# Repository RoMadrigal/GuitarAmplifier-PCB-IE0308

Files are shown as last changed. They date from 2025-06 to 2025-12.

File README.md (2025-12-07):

# GuitarAmplifier-PCB-IE0308

Repositorio para el proyecto final del curso IE0308 sobre el diseño de una PCB de un amplificador para guitarra. Contiene el circuito esquemático, el diseño de la PCB en *KiCad* y documentación sobre los componentes a utilizar, el procedimiento de diseño y otros detalles. 

Este repositorio y sus contenidos fueron diseñados durante el curso IE0308 durante el periodo I-2025 por los siguientes integrantes del equipo:

<div align="center">

| **Integrantes** | **Carné** | **Correo electrónico**|
|:---:|:---:|:---:|
| Anthony Calvo García | C11433  |  anthonycalvo50@gmail.com |
| Rodrigo Madrigal Montes | C24458  | rmadrigalmontes@gmail.com |

</div>

## Agradecimientos a PCBWay

Queremos expresar nuestro agradecimiento a **PCBWay** por su colaboración y apoyo en la fabricación de nuestras PCBs. La calidad de las placas recibidas, tanto en precisión de fabricación como en acabados, fue sobresaliente. Todo el proceso desde la carga de archivos hasta la recepción del paquete fue ágil, transparente y eficiente. 

Además siempre estuvieron disponibles para cualquier consulta, para asegurarse de que todo saliera según lo planeado, lo cual nos brindó mucho soporte y seguridad durante todo el proceso de pedido.

### PCB ensamblada

Una vez recibidas las placas de **PCBWay**, se procedió con el ensamblaje manual de todos los componentes. A continuación se muestran imágenes del resultado final:

<div align="center">

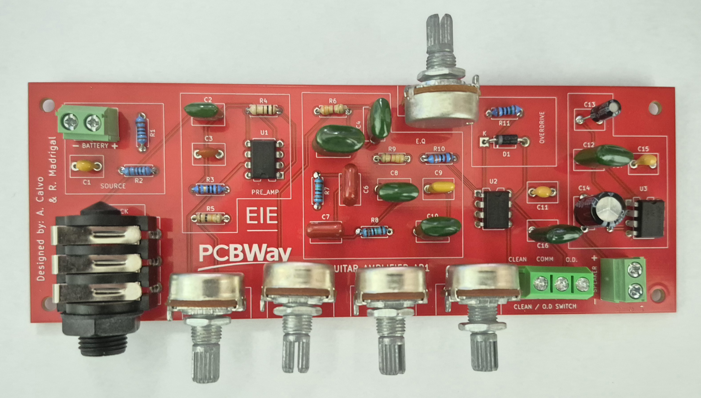
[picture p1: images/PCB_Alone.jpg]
PCB ensamblada - sin los componentes externos conectados
|  |
|:--:|
| *PCB ensamblada - sin los componentes externos conectados* |

</div>

<div align="center">

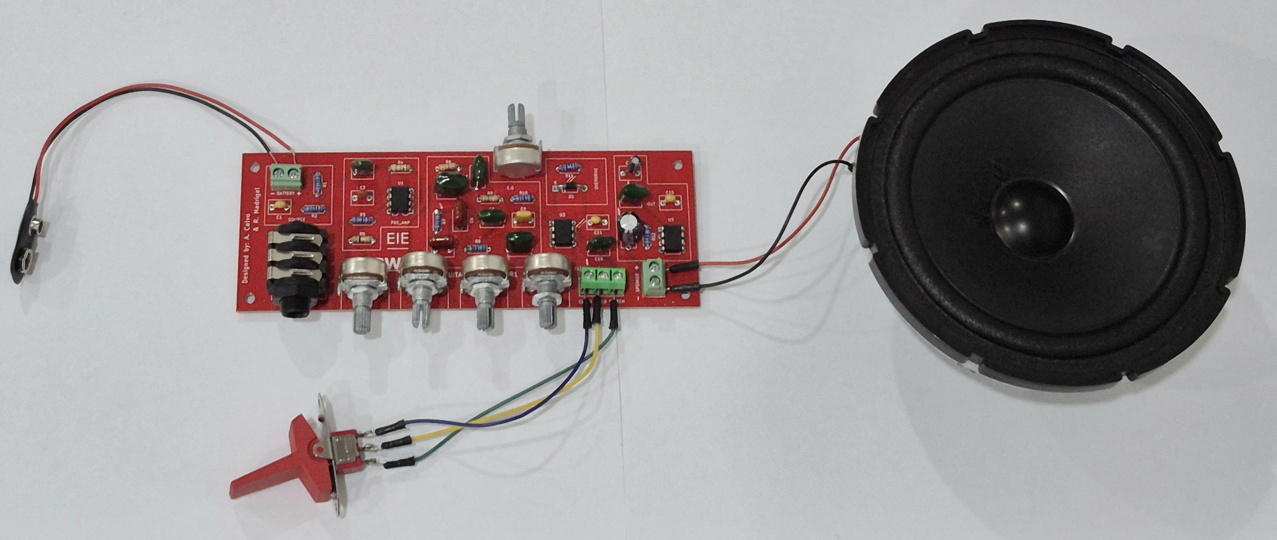
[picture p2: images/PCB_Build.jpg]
PCB ensamblada - con los componentes externos conectados
|  |
|:--:|
| *PCB ensamblada - con los componentes externos conectados* |

</div>

### Demostración de funcionamiento

A continuación, se presentan vídeos demostrativos del amplificador montado, funcionando correctamente tanto con una guitarra eléctrica como con un teléfono:

<p align="center">
  <a href="https://youtu.be/fU8gYd2I1fY" target="_blank">
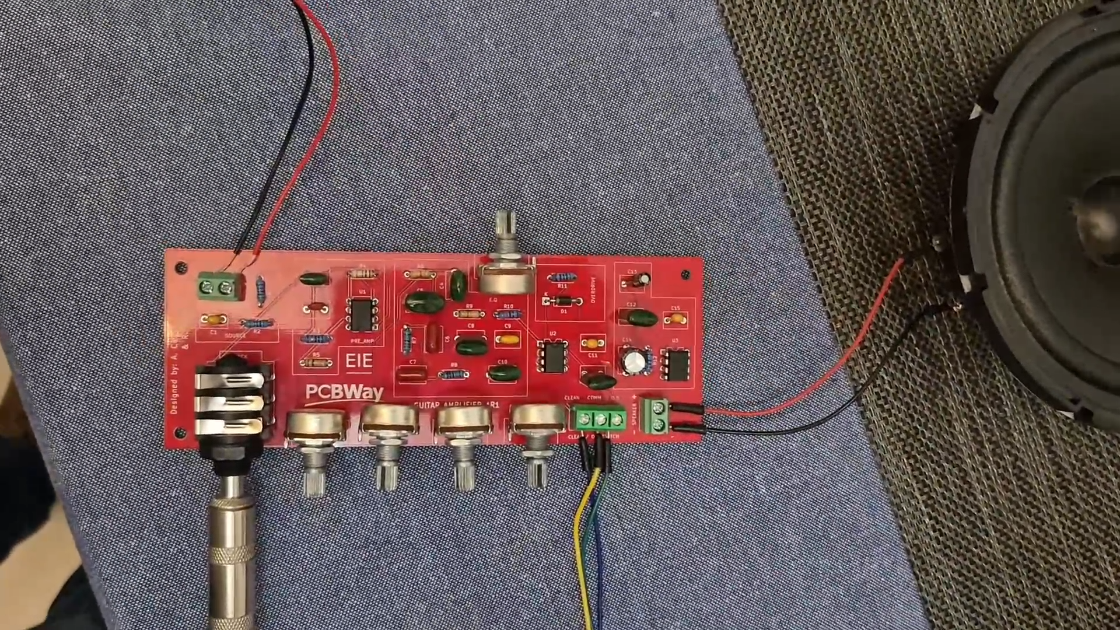
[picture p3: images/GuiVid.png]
Demo con guitarra eléctrica
    
  </a>
  <br/>
  <em>Demostración del amplificador conectado a una guitarra eléctrica</em>
</p>

<p align="center">
  <a href="https://youtu.be/jr76lwe1I88" target="_blank">
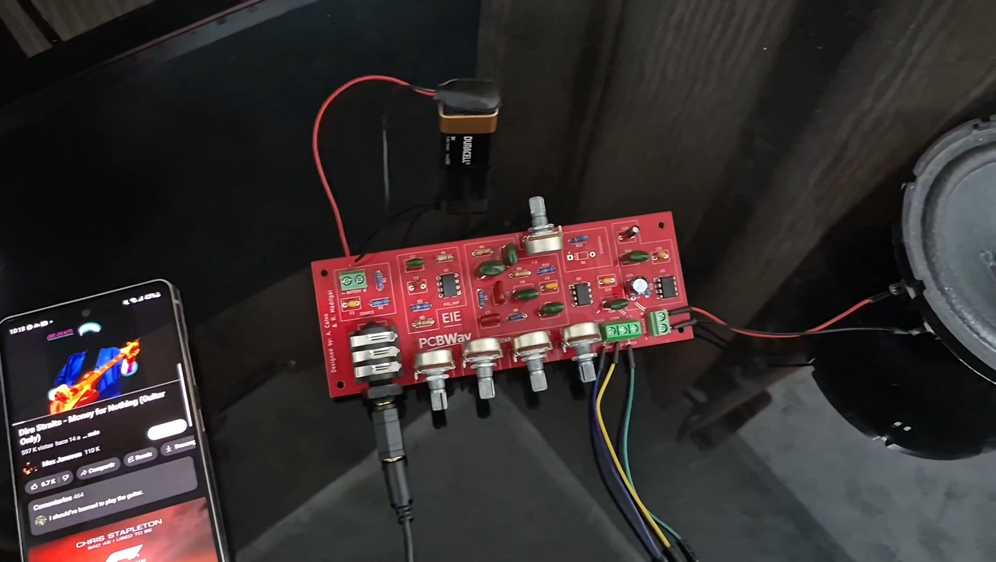
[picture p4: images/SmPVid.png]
Demo con teléfono móvil
    
  </a>
  <br/>
  <em>Demostración del amplificador reproduciendo audio desde un teléfono</em>
</p>

Gracias a su servicio confiable y de altísima calidad, logramos ensamblar y probar con éxito nuestro amplificador, cumpliendo los objetivos del proyecto. Recomendamos sus servicios para estudiantes, profesionales y cualquier persona interesada en manufacturar PCBs de alta calidad. Más información en [pcbway.com](https://www.pcbway.com).

## Organización y contenido de los directorios 

Este repositorio contiene dos directorios principales, cuyos contenidos son:

- `kicad_project`: Contiene los archivos del esquemático, PCB y la configuarción del proyecto
    - `GuitarAmplifier.kicad_pcb`
    - `GuitarAmplifier.kicad_pro`
    - `GuitarAmplifier.kicad_sch`

- `outputs`: Contiene todos los archivos de salida de *KiCad*

Si se desea utilizar este diseño y manufacturarlo por medio de un fabricante se deben comprimir los archivos incluidos en la carpeta `outputs` en un archivo `.zip` y este se puede cargar en la página del fabricante para ordenar la fabricación de la PCB.

## Circuito base

El circuito completo del que partimos para diseñar la PCB fue primeramente fue armado y simulado en el simulador *Tina-TI*:

<div align="center">

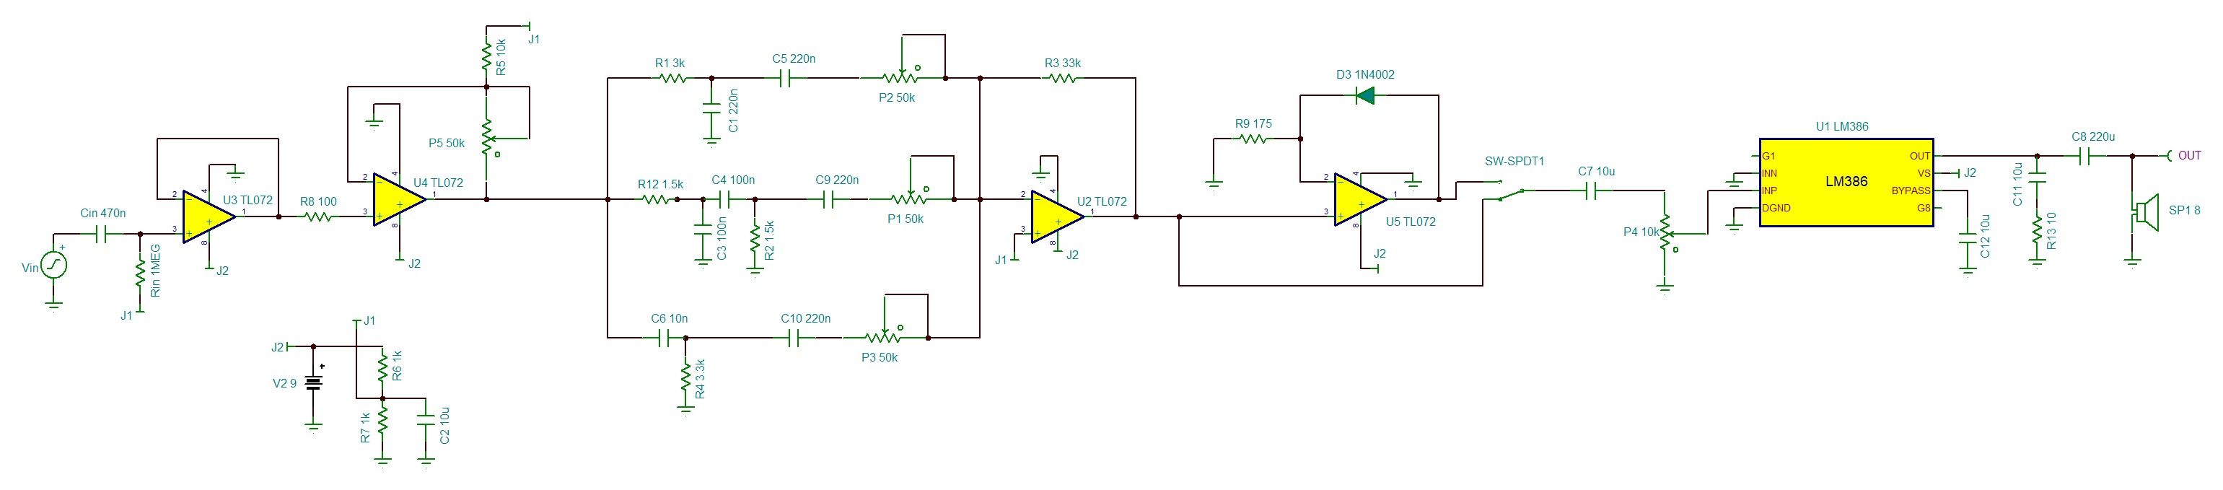
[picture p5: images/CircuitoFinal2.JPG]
Circuto completo del diseño*
|  |
|:--:|
| *Circuto completo del diseño* |

</div>

> [!NOTE]
> La documentación detallada de funcionamiento de cada etapa del circuito, elección de componentes, y consideraciones de diseño está disponible en la documentación adicional asociada al proyecto (ver `Wiki` de este repostitorio).

### Lista de componentes

A continuación se incluye una lista con los componentes utilizados en el diseño, con el mismo número que se les asignó en el diseño final de PCB:

<div align="center">

| Componente | Valor / Modelo | Descripción |
|:---:|:---:|:---:|
| R1 / R2 | 1 kΩ | Resistor de película metálica |
| R3 | 1 MΩ | Resistor de película metálica |
| R4 | 100 Ω | Resistor de película metálica |
| R5 | 10 kΩ | Resistor de película metálica |
| R6 | 3 kΩ | Resistor de película metálica |
| R7 / R8 | 1.5 kΩ | Resistor de película metálica |
| R9 | 3.3 kΩ | Resistor de película metálica |
| R10 | 33 kΩ | Resistor de película metálica |
| R11 | 170 Ω | Resistor de película metálica |
| R12 | 10 Ω | Resistor de película metálica |
| C1 / C3 / C11 / C15 | 470 nF | Capacitor cerámico |
| C2 / C6 / C7 / C12 | 100 nF | Capacitor de poliéster |
| C4 / C5 / C8 / C10 / C16 | 220 nF | Capacitor de poliéster |
| C9 | 10 nF | Capacitor de poliéster |
| C13 | 10 μF | Capacitor electrolítico |
| C14 | 220 μF | Capacitor electrolítico |
| U1 / U2 | TL072CP | Amplificador operacional |
| U3 | LM386 | Amplificador de potencia |
| D1 | 1N4148 | Diodo rectificador |
| Gain / Low / Mid / High | 50 kΩ | Potenciómetro logarítmico |
| Volume | 10 kΩ | Potenciómetro logarítmico |
| J1 | - | Jack estéreo 6,3 mm |
| Battery / Speaker | - | Terminal 01x02 5.08mm |
| Clean / O.D. Switch | - | Terminal 01x03 5.08mm |

</div>

## Diseño de la PCB

Una vez definido el circuito final, se diseñó la PCB en *KiCad* con una arquitectura de **cuatro capas**:

- **F.Cu**: Ruta de señales
- **In1.Cu**: Plano de alimentación (+9V y +4.5V)
- **In2.Cu**: Plano de tierra (GND)
- **B.Cu**: Ruta de señales

### Capas de la PCB

<div align="center">

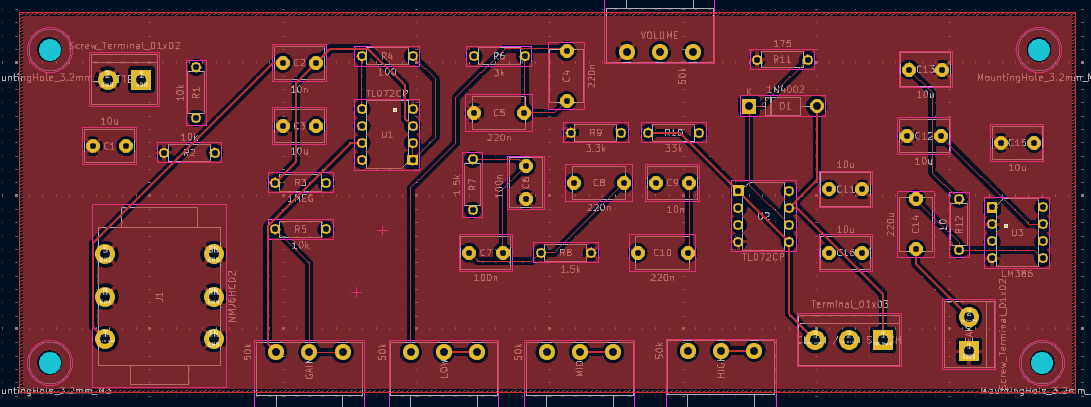
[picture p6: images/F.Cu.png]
Capa F.Cu
|  |
|:-----------------------------:|
|    *Capa superior (F.Cu)*     |

</div>

<div align="center">

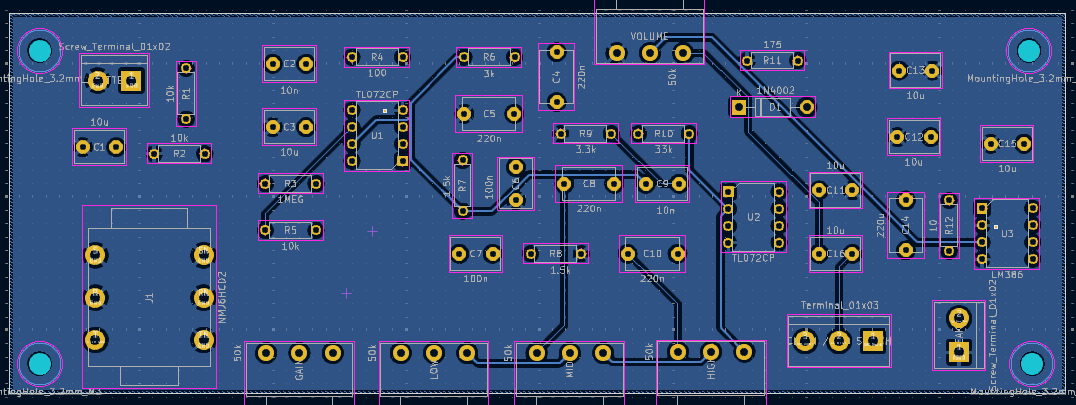
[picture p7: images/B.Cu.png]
Capa B.Cu
|  |
|:-----------------------------:|
|    *Capa inferior (B.Cu)*     |

</div>

<div align="center">

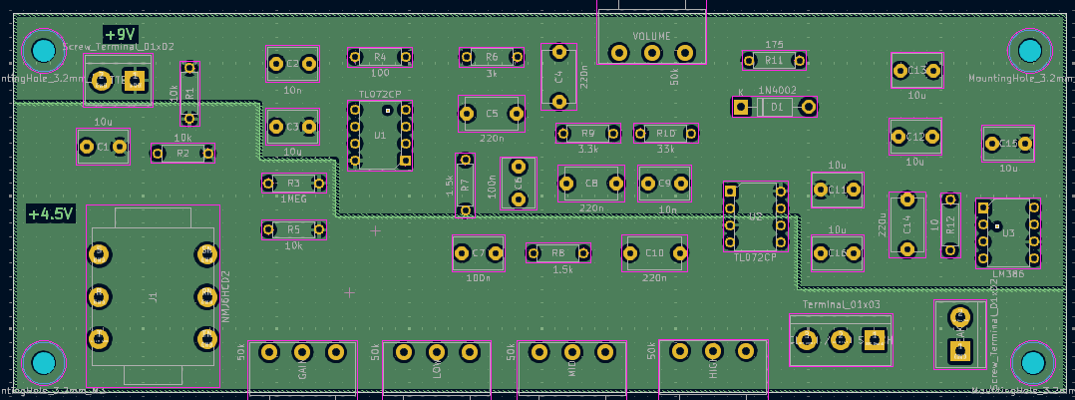
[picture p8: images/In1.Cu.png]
In1.Cu - Alimentación
|  |
|:-------------------------------------------:|
|      *Capa interna 1 - +9V / +4.5V*         |

</div>

<div align="center">

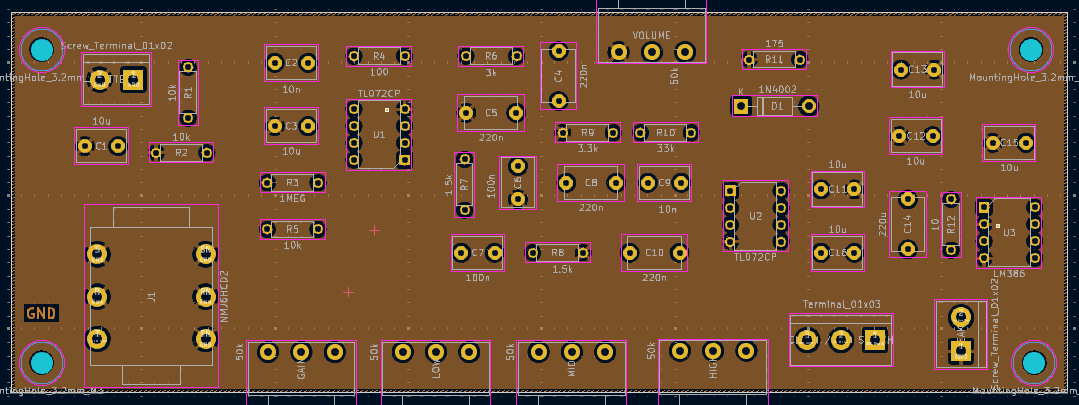
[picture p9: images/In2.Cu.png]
In2.Cu - Tierra
|  |
|:-------------------------------------:|
|        *Capa interna 2 - GND*         |

</div>

Además, se agregaron zonas de serigrafía, agujeros de montaje, así como textos identificativos y logotipos en el *silkscreen* con el nombre del proyecto y los autores. Como resultado final se muestra la PCB en el visor 3D de *KiCad* con y sin los modelos 3D 

<div align="center">

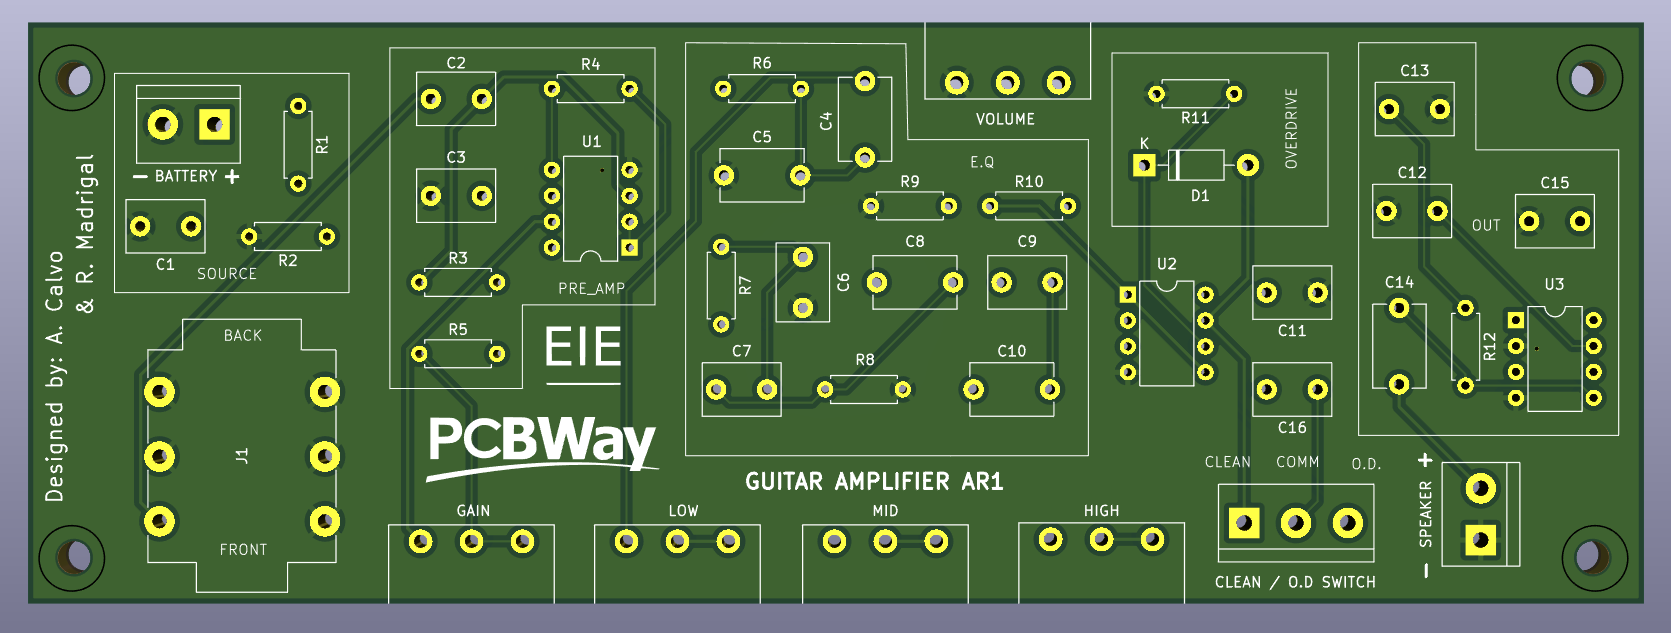
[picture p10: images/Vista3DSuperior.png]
Vista 3D Frontal de la PCB sin 3D
|  |
|:--:|
| *Vista 3D Frontal de la PCB en KiCad* |

</div>

<div align="center">

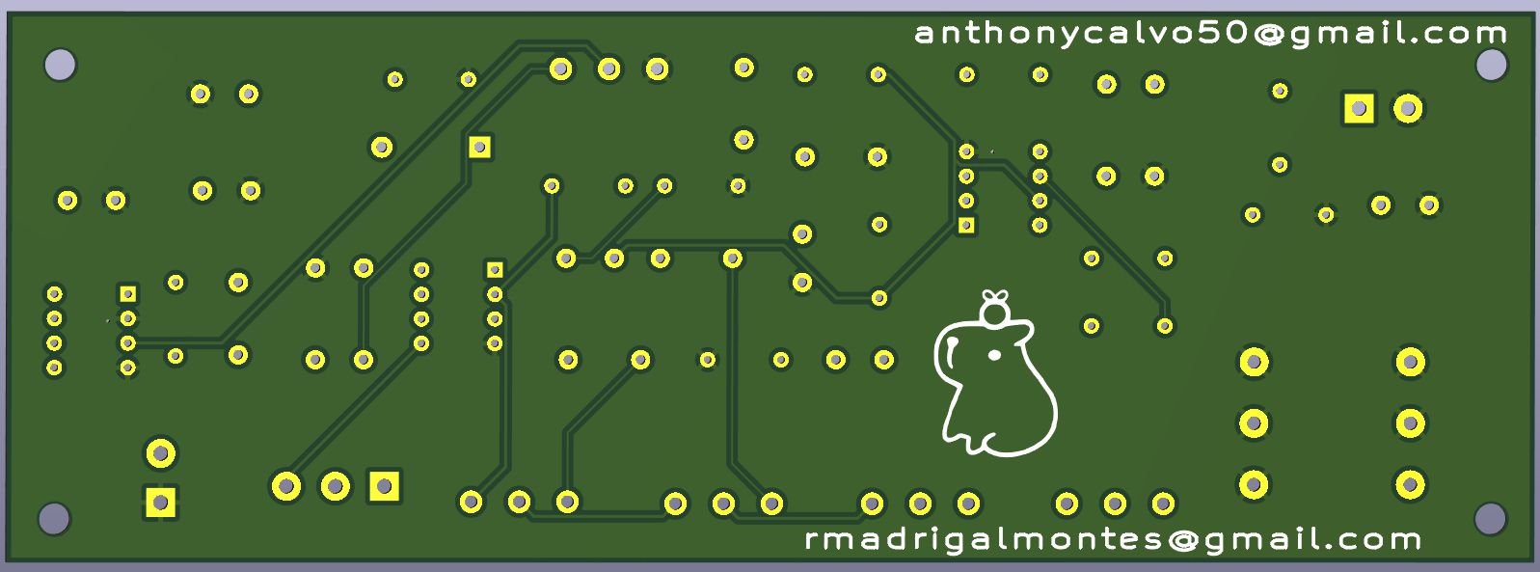
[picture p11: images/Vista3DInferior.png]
Vista 3D Trasera de la PCB sin 3D
|  |
|:--:|
| *Vista 3D Trasera de la PCB en KiCad* |

</div>

<div align="center">

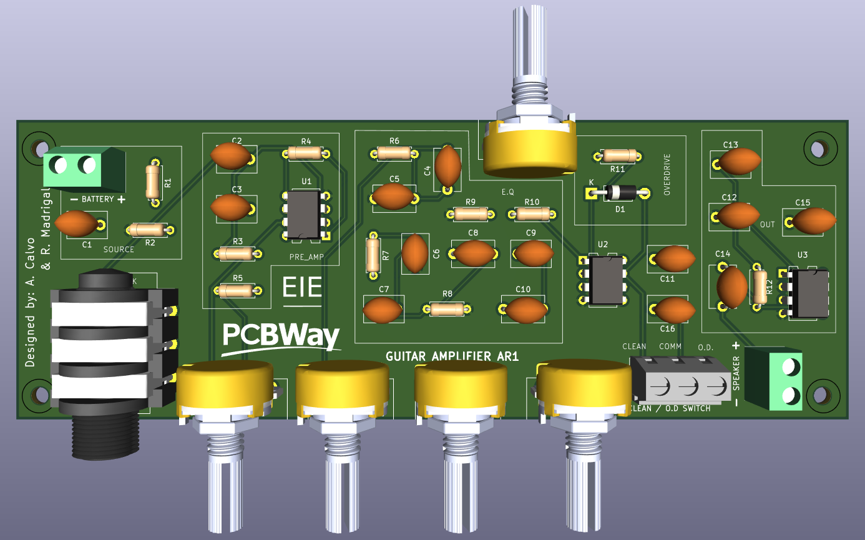
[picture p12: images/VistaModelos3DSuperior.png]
Vista 3D Frontal de la PCB con 3D
|  |
|:--:|
| *Vista 3D Frontal de la PCB en KiCad con modelos 3D* |

</div>

<div align="center">

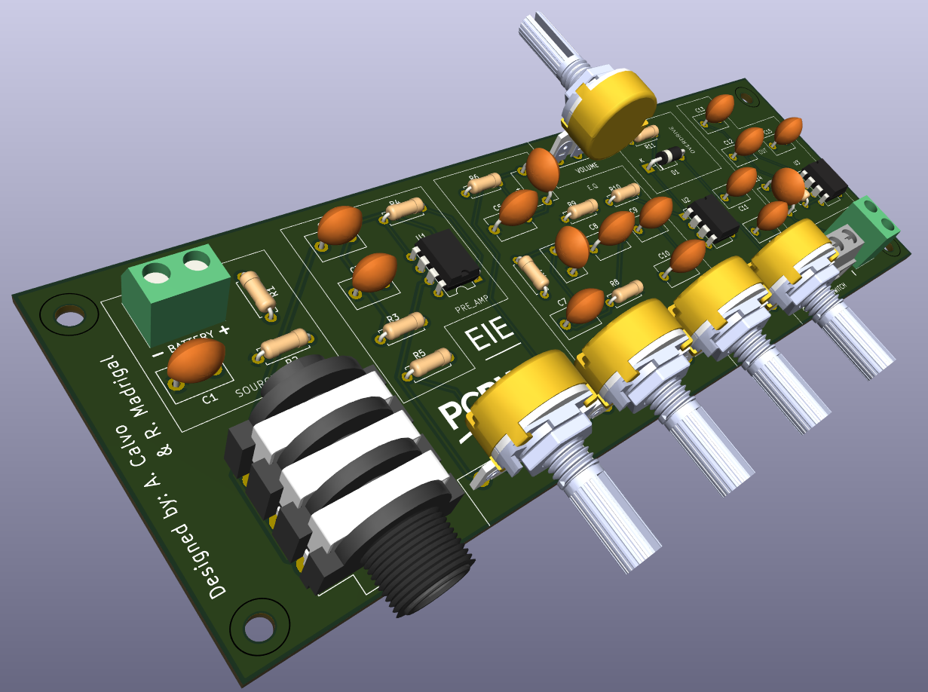
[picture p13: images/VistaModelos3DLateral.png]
Vista 3D Lateral Izquierda de la PCB con 3D
|  |
|:--:|
| *Vista 3D Lateral Izquierda de la PCB en KiCad con modelos 3D* |

</div>

<div align="center">

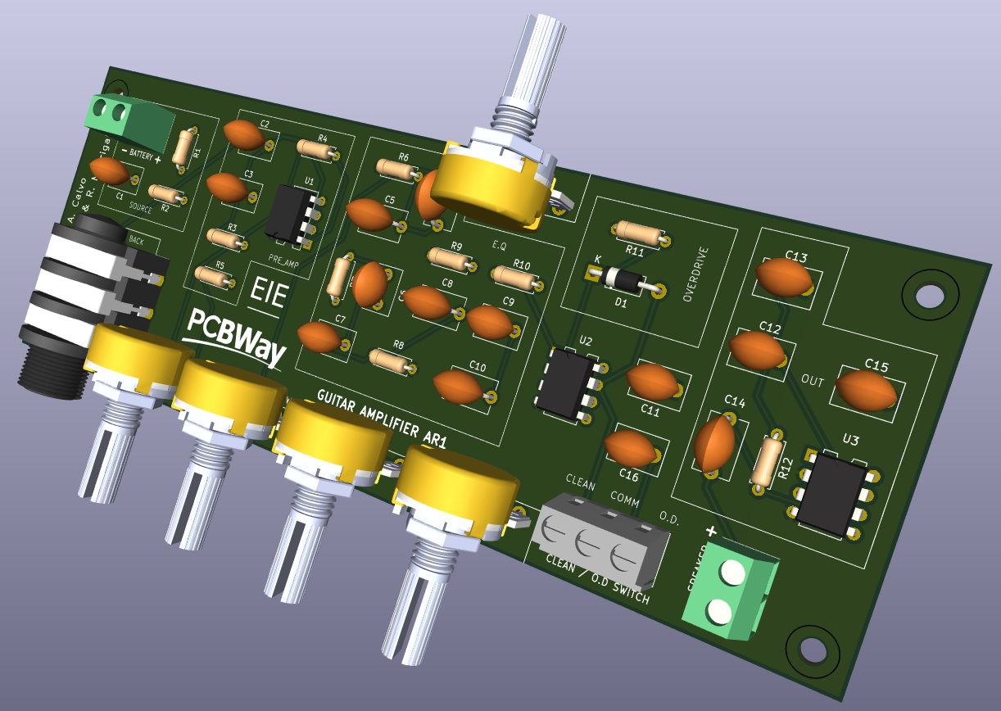
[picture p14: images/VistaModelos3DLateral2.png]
Vista 3D Lateral Derecha de la PCB con 3D
|  |
|:--:|
| *Vista 3D Lateral Derecha de la PCB en KiCad con modelos 3D* |

</div>

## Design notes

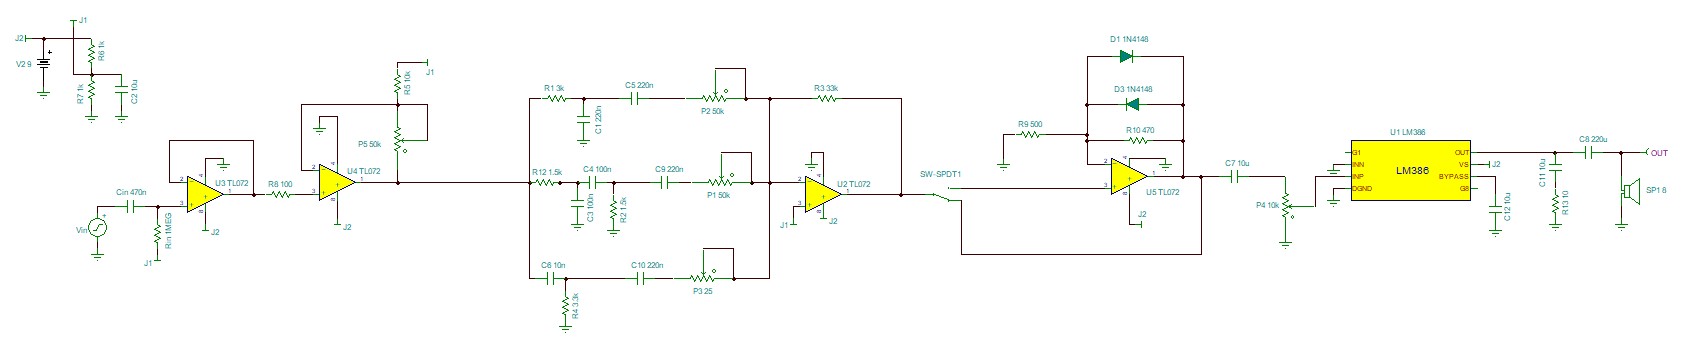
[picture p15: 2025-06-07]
images/CircuitoFinal.JPG

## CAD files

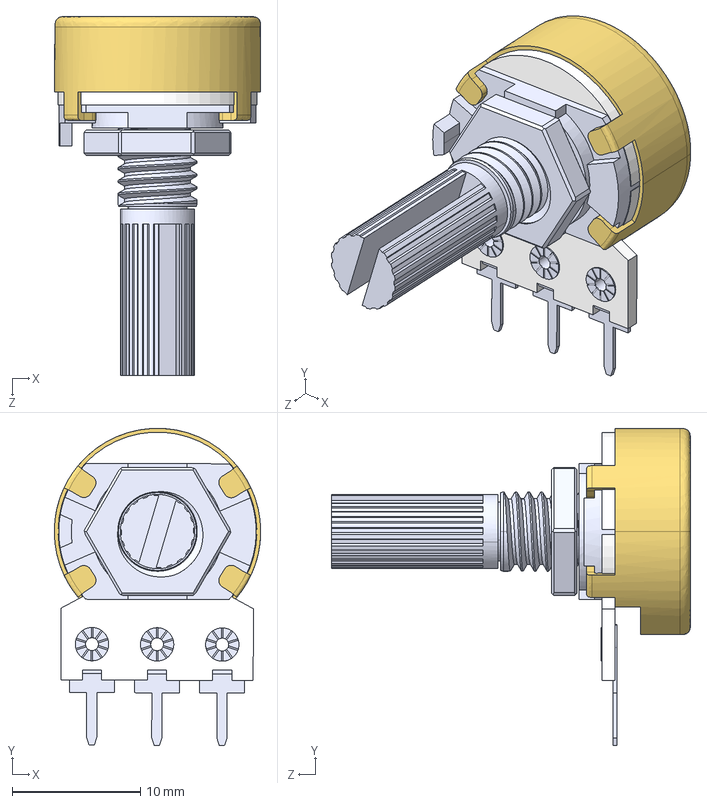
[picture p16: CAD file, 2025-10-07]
kicad_project/3Dmodels/PotentiometerAssy.STEP
16.1 x 24.7 x 28.0 mm
PotentiometerCasing
PotentiometerPCB
PotentiometerShaft
PotentiometerTerminal x 3
PotentiometerThreadPlate
PotentiometerNut

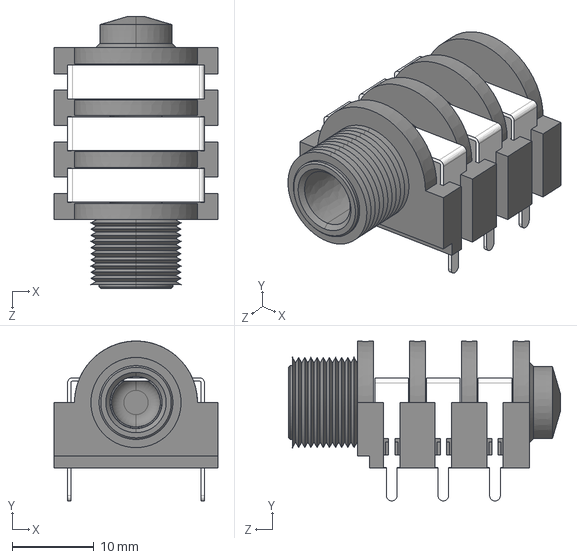
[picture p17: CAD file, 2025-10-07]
kicad_project/3Dmodels/SJ-63073E--3DModel-STEP-1.STEP
20.0 x 19.5 x 33.2 mm

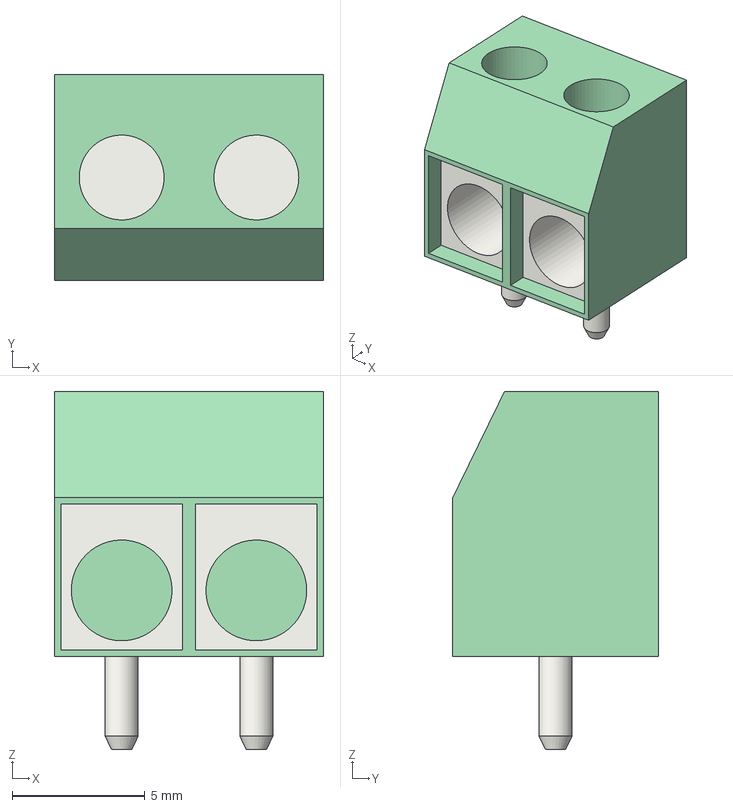
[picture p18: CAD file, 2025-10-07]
kicad_project/3Dmodels/TerminalBlock_bornier-2_P5.08mm.step
10.2 x 7.75 x 13.5 mm

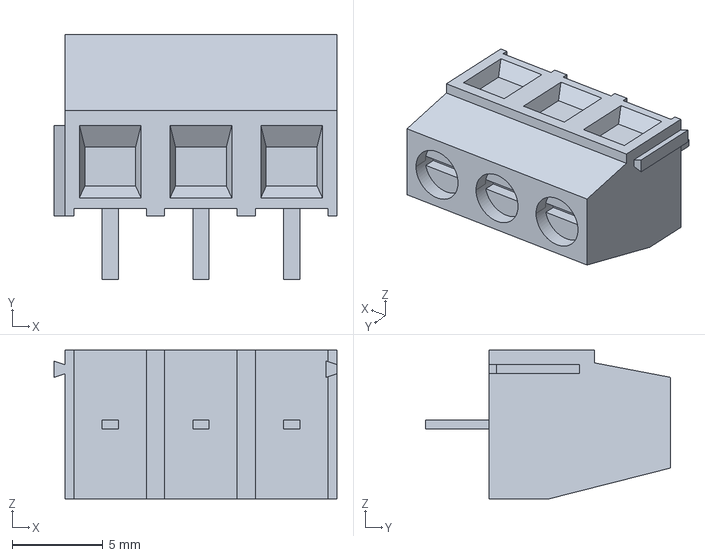
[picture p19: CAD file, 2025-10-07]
kicad_project/3Dmodels/282836-3--3DModel-STEP-1.STEP
15.6 x 13.5 x 8.20 mm

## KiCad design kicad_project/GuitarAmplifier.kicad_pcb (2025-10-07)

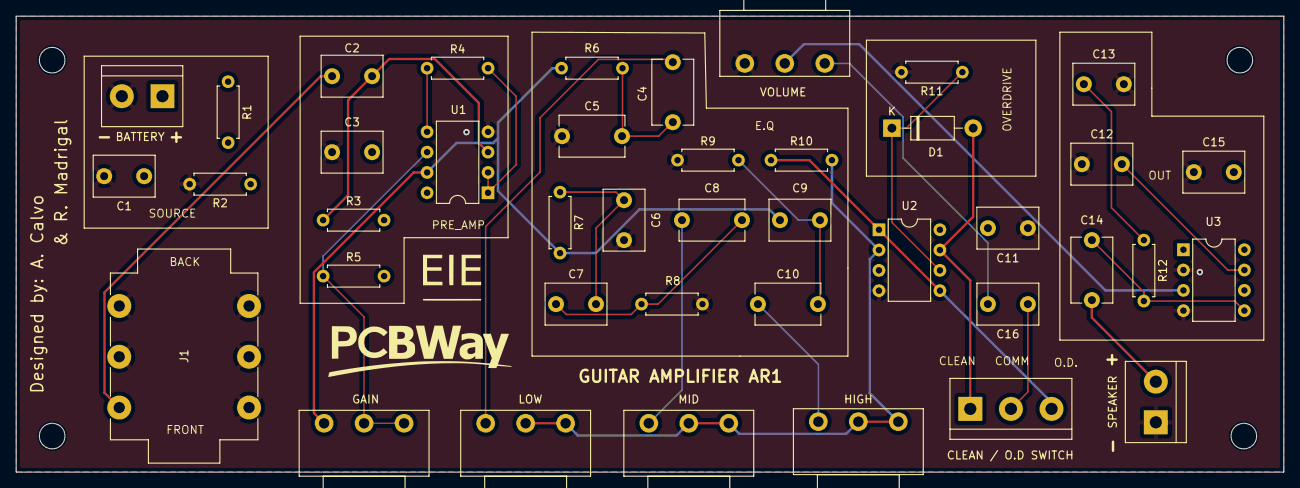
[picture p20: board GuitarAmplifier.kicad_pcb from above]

Board: 4 copper layers, 158.5 x 57.0 mm, 45 parts (0 on the bottom side), 27 nets.

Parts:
BATTERY: Screw_Terminal_01x02; TerminalBlock_bornier-2_P5.08mm
C1, C3, C11, C12, C13, C15, C16: 10u; C_Disc_D7.5mm_W5.0mm_P5.00mm
C2, C9: 10n; C_Disc_D7.5mm_W5.0mm_P5.00mm
C4, C5, C8, C10: 220n; C_Disc_D8.0mm_W5.0mm_P7.50mm
C6, C7: 100n; C_Disc_D7.5mm_W5.0mm_P5.00mm
C14: 220u; C_Disc_D8.0mm_W5.0mm_P7.50mm
CLEAN / O.D SWITCH: Terminal_01x03; TerminalBlock_bornier-3_P5.08mm
D1: 1N4002; D_DO-41_SOD81_P10.16mm_Horizontal
GAIN: 50k; Potentiometer_Piher_PC-16_Single_Horizontal
H1, H2, H3, H4: MountingHole_3.2mm_M3
HIGH: 50k; Potentiometer_Piher_PC-16_Single_Horizontal
J1: NMJ6HCD2; Jack_6.35mm_Neutrik_NMJ6HCD2_Horizontal
LOW: 50k; Potentiometer_Piher_PC-16_Single_Horizontal
MID: 50k; Potentiometer_Piher_PC-16_Single_Horizontal
R1, R2, R5: 10k; R_Axial_DIN0207_L6.3mm_D2.5mm_P7.62mm_Horizontal
R3: 1MEG; R_Axial_DIN0207_L6.3mm_D2.5mm_P7.62mm_Horizontal
R4: 100; R_Axial_DIN0207_L6.3mm_D2.5mm_P7.62mm_Horizontal
R6: 3k; R_Axial_DIN0207_L6.3mm_D2.5mm_P7.62mm_Horizontal
R7, R8: 1.5k; R_Axial_DIN0207_L6.3mm_D2.5mm_P7.62mm_Horizontal
R9: 3.3k; R_Axial_DIN0207_L6.3mm_D2.5mm_P7.62mm_Horizontal
R10: 33k; R_Axial_DIN0207_L6.3mm_D2.5mm_P7.62mm_Horizontal
R11: 175; R_Axial_DIN0207_L6.3mm_D2.5mm_P7.62mm_Horizontal
R12: 10; R_Axial_DIN0207_L6.3mm_D2.5mm_P7.62mm_Horizontal
SPEAKER: Screw_Terminal_01x02; TerminalBlock_bornier-2_P5.08mm
U1, U2: TL072CP; DIP-8_W7.62mm
U3: LM386; DIP-8_W7.62mm
VOLUME: 50k; Potentiometer_Piher_PC-16_Single_Horizontal

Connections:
+4.5V: C1.1, R1.2, R2.1, R3.2, R5.2, U2.3 (1IN+)
+9V: BATTERY.1, C3.2, C11.2, C15.2, R1.1, U1.8 (VCC+), U2.8 (VCC+), U3.6 (V+)
/OUT_Clean: CLEAN / O.D SWITCH.3, R10.1, U2.1 (1OUT), U2.5 (2IN+)
/OUT_Eq: HIGH.2, HIGH.3, LOW.2, LOW.3, MID.2, MID.3, R10.2, U2.2 (1IN-)
/OUT_OverD: CLEAN / O.D SWITCH.1, D1.2 (A), U2.7 (2OUT)
/OUT_PreAmp: C9.2, GAIN.1, R6.2, R7.2, U1.7 (2OUT)
/System_Out: C14.2, SPEAKER.2
GND: BATTERY.2, C1.2, C3.1, C5.1, C6.1, C11.1, C12.1, C13.2, C15.1, J1.R, J1.RN, J1.S, J1.SN, J1.TN, R2.2, R8.1, R9.1, R11.2, SPEAKER.1, U1.4 (VCC-), U2.4 (VCC-), U3.2 (-), U3.4 (GND), VOLUME.3
unnamed: C2.2, J1.T
unnamed: C4.1, LOW.1
unnamed: C4.2, C5.2, R6.1
unnamed: C6.2, C7.2, R7.1
unnamed: C7.1, C8.2, R8.2
unnamed: C8.1, MID.1
unnamed: C10.1, HIGH.1
unnamed: C9.1, C10.2, R9.2
unnamed: C13.1, R12.1
unnamed: C14.1, R12.2, U3.5
unnamed: C16.2, VOLUME.1
unnamed: D1.1 (K), R11.1, U2.6 (2IN-)
unnamed: C16.1, CLEAN / O.D SWITCH.2
unnamed: C2.1, R3.1, U1.3 (1IN+)
unnamed: R4.2, U1.1 (1OUT), U1.2 (1IN-)
unnamed: R4.1, U1.5 (2IN+)
unnamed: GAIN.2, GAIN.3, R5.1, U1.6 (2IN-)
unnamed: U3.3 (+), VOLUME.2
unnamed: C12.2, U3.7 (BYPASS)

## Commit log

2025-06-07 Agregando tipos de archivos adicionales al .gitignore
2025-06-07 Agregando imagen del circuito final en el directorio images
2025-06-13 Se agregan las etapas de alimentacion, buffer y pre-amp
    [GuitarAmplifier.kicad_pcb, GuitarAmplifier.kicad_sch]
2025-06-13 Agregando etapa de ecualizacion
    [GuitarAmplifier.kicad_sch]
2025-06-14 Agregando informacion de contacto y sobre el circuito base en el README.md
2025-06-14 Agregando nota de la documentacion detallada en el README.md
2025-06-15 Agregando el overdrive, la etapa de salida ambas verificadas y una representación casi finalizada de la PCB
    [GuitarAmplifier.kicad_pcb, GuitarAmplifier.kicad_sch]
2025-06-15 Realizando acomodo final en el esquematico y PCB
    [GuitarAmplifier.kicad_pcb, GuitarAmplifier.kicad_sch]
2025-06-15 Definiendo las capas de alimentacion y tierra en la PCB
    [GuitarAmplifier.kicad_pcb, GuitarAmplifier.kicad_sch]
2025-06-16 Conectando pistas y vias en la capa superior de la PCB
    [GuitarAmplifier.kicad_pcb]
2025-06-16 Agregando el enrutamiento final y una reconfiguración de la placa
    [GuitarAmplifier.kicad_pcb, GuitarAmplifier.kicad_sch]
2025-06-16 Terminando de rellenar la capa inferior y ajustando las huellas de los conectores
    [GuitarAmplifier.kicad_pcb, GuitarAmplifier.kicad_sch]
2025-06-16 Agregando detalles finales en la serigrafia de la PCB
    [GuitarAmplifier.kicad_pcb]
2025-06-16 Reasignando huella de los potenciometros
    [GuitarAmplifier.kicad_pcb, GuitarAmplifier.kicad_sch]
2025-06-16 Agregando logotipos y verificando la configuracion final
    [GuitarAmplifier.kicad_pcb]
2025-06-17 Agregando carpeta outputs con los archivos gerber y .drl
    [GuitarAmplifier-B_Cu.gbl, GuitarAmplifier-B_Mask.gbs, GuitarAmplifier-B_Paste.gbp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]
2025-07-05 Agregando secciones de diseño y agradecimiento a PCBWay en el README.md
2025-07-05 Modificando ubicación de las imagenes de la PCB en el README.md
2025-07-05 Agregando lista de componentes y corrigiendo errores en el README.md
2025-07-05 Agregando seccion de videos demostrativos al README.md
2025-07-06 Agregando imagenes del resultado final y disenyo en Kicad al README.md
2025-07-06 Agregando las imagenes del README.md en el directorio images
2025-07-06 Agregando enlaces a videos demostrativos del funcionamiento en el README.md
2025-07-06 Agregando tabla de componentes en el README.md
2025-07-06 Corrigiendo detalles finales en el README.md
2025-08-08 Agregando serigrafia trasera
    [GuitarAmplifier.kicad_pcb]
2025-08-08 Agregando foto de la vista trasera
2025-08-08 Agregando foto de la vista trasera al README
2025-09-25 Agregando imagenes con modelos 3D en el README.md
2025-09-25 Agregando cambio en conector de switch y modelos 3D de componentes faltantes
    [282836-3--3DModel-STEP-1.STEP, GuitarAmplifier.kicad_pcb, PotentiometerAssy.STEP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]
2025-09-25 Agregando archivos actualizados de fabricacion
    [GuitarAmplifier-B_Cu.gbl, GuitarAmplifier-B_Mask.gbs, GuitarAmplifier-B_Paste.gbp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]
2025-10-07 Se corrigio la Vista3DInferior
    [GuitarAmplifier.kicad_pcb]
2025-10-07 Corrigiendo imagen de la vista3DInferior
2025-12-07 Corrigiendo un error en la seccion: Organizacion y contenido de los directorios
